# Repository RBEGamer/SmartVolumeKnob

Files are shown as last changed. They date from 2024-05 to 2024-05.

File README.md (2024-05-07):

# SmartVolumeKnob

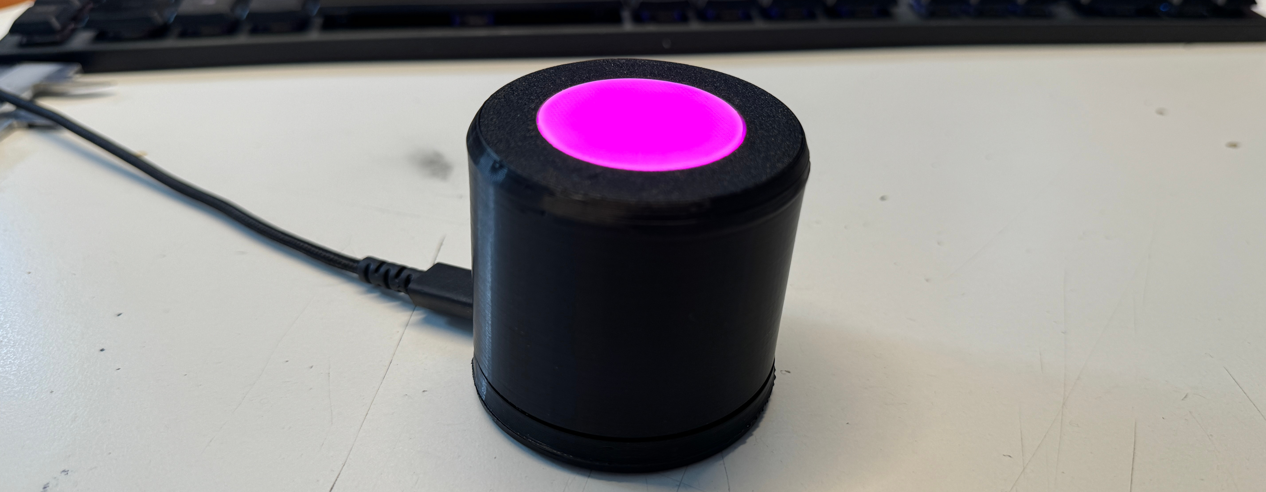
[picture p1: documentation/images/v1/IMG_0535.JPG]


Experience a revolutionary gaming experience with our 3D-printed Fidget Volume Knob!
Bring your music to life and heighten your sensory perception with every twist.
The LED effects add a visual dimension that lights up your room and lifts your mood. Perfect for audiophiles, gamers and anyone who wants to keep their fingers busy.
Get the ultimate companion for your music and gaming session today!

## FEATURES

* Interactive design: Twist, feel and enjoy - The Fidget Volume Knob offers a tactile experience that engages your fingers and stimulates your senses.
High quality material: Made from durable and lightweight 3D printed material that is both sturdy and aesthetically pleasing.
* Compatibility: The Volume Knob is compatible with a wide range of devices, including speaker systems, amplifiers, computers and more. Advanced compatibility allows you to utilize the full potential of your audio equipment.
* Simple setup: Setup is a breeze and requires no special tools. Only a 3D printer some screws and wires are needed for construction. Software is plug&play.
* Ergonomic design: The ergonomic design of the volume knob ensures comfortable handling and a comfortable gaming experience, whether you're listening to music for hours or enjoying intense gaming sessions.
* Stylish design: With its modern and futuristic design, the Fidget Volume Knob is not only a functional accessory, but also an eye-catcher in any room.
* Versatile use: Whether for listening to music, gaming or simply to relieve stress - the Fidget Volume Knob with LED effects is a versatile accessory that is suitable for any occasion. Thanks to the microcontroller used, all kinds of functions can be realized.

## BOM 

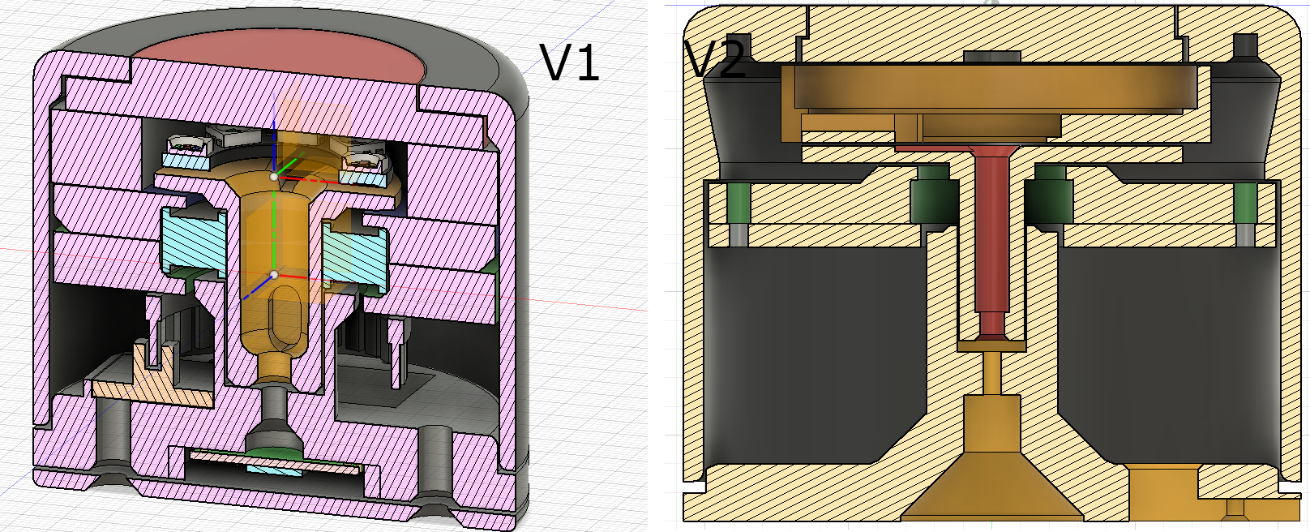
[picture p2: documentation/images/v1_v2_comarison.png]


Currently there are two different versions of the `SmartVolumeKnob` labeled  `v1` and `v2`.
The key difference is the size and complexity of the mechanical strucutre.

`V1` is the small variant of the `SmartVolumeKnob` with a footprint of arounf `60mm` in diameter, but the mechanical parts are designed with limited tolerances.
It uses a 3d printed optical encoder consists of one encoder disc and two light barrier modules to form a incremental encoder.

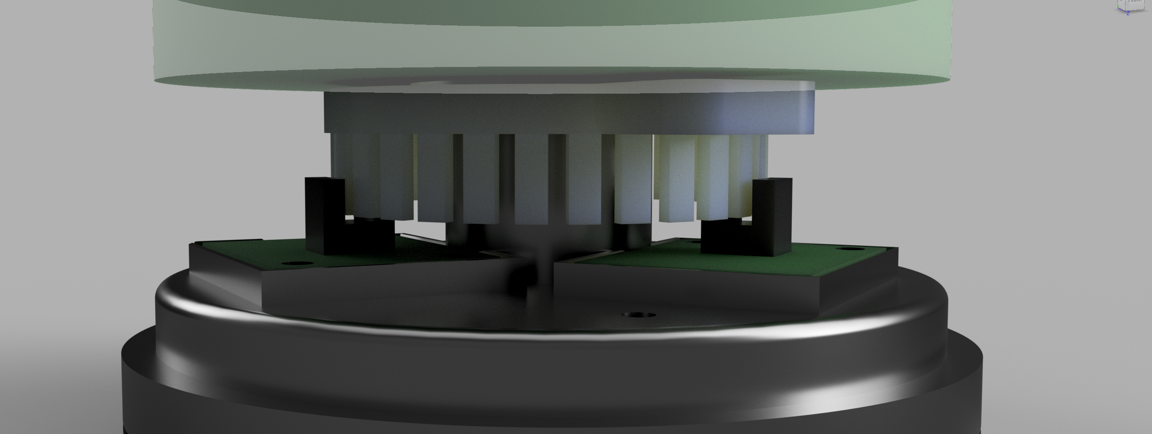
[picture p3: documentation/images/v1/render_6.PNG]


The `V2` is a huge and more simplified design with a footprint of around `110mm` in diameter.
To further simplify the design a magnetic absolute encoder is used here instead of the more complicated diy encoder design.

### GENERAL 3D PRINT SETTINGS AND POST PROCESSING STEPS

* Layer height: 0.2mm or 0.1mm for better shell quality
* Support: Support on buildplate only
* Inflill: 10% - 20%
* The screw holes are designed without any large tolerances. So may run a X-Y compensation on your printer first or drill them to size after printing.

For additional haptic and quality improvement, you can print the * `*_shell.stl` parts using a SLA / SLS printer!

All exported `.stl` files can be found in the `src/cad/<VARIANT>/stl`. All parts as `.step` and the `Fusion360` project files can be found in the parent folder.

After printing all parts use an `debringing tool` on all parts with inner holes ( especially on `bearing_*.stl` parts).

### REQUIRED FILAMENT

For both versions there are at least two different filament colors required. One for the base color of the shell and one for the lightpath (`white`/`transparent`)
For all inner parts the color can be anything, due these are not visible from the outside.
`PLA` is used on all 3D printed parts here. All files are designed for a  `120x120x190mm` buildplate, such as the `Voron V0`.

* accent color for outher shell - `shell_*.stl` and `bottom*.stl`, `baseplate*.stl`
* transparent or white for the lightguide parts - `illuminator_*.stl`
* unspecified color - all other `*.stl` files

### REQUIRED TOOLS

* Soldering Iron
* Cables
* Superglue
* Debringing tool
* Small zip ties
* Some wires to connect the individual modules
* Micro USB cable
  
### V2

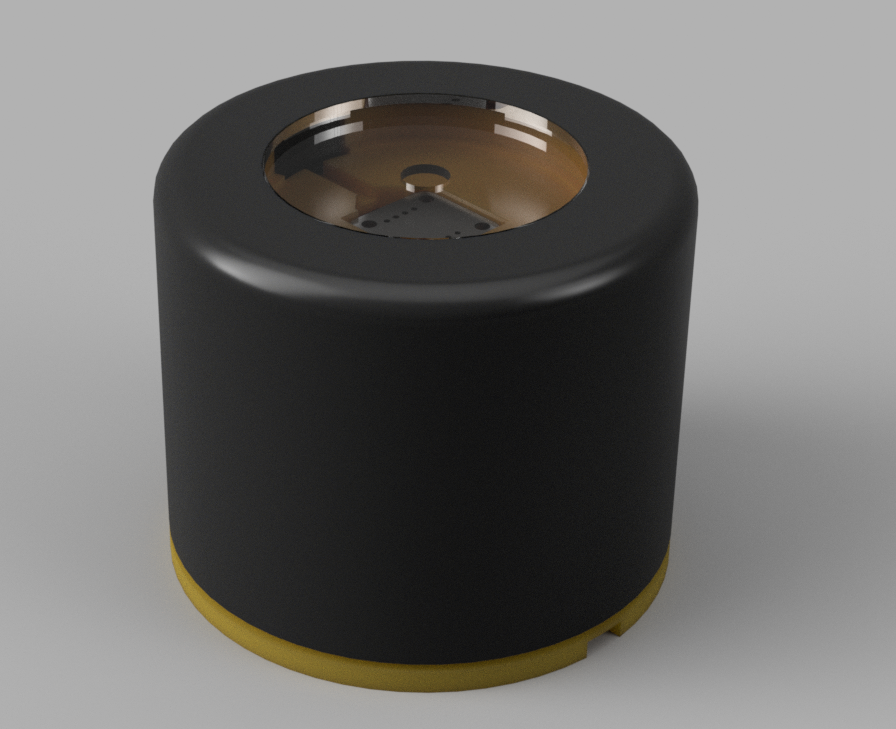
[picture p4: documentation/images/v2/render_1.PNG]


#### 3D PRINTED PARTS

* 1x `electronic_bay.stl`
* 1x `electronic_clamp.stl`
* 1x `bottom.stl`
* 1x `bearing_mount_bottom.stl`
* 1x `bearing_mount_top.stl`
* 1x `illuminator_bearing_connector.stl`
* 1x `illuminator_bottom.stl` - Lightguide - use white or transparent filament!
* 1x `illumniator_top.stl` - Lightguide - use white or transparent filament!
* 1x `outher_shell.stl`
* 1x `illuminator_spacer.stl` - optional but helps a lot with assembly

#### MECHANICAL

* 13x Heat inserts` M3 Short`
* 1x Bearing `6001RS 12mm x 28mm x 8mm`
* 9x `M3x10 FHCS`
* 4x `M3x40 SHCS`
* 2x - 4x `M2x8` to secure the `Raspberry Pi Pico`, or just use a bit of hotglue or superglue
* `aluminium foil` for the light reflector

#### ELECTRICAL

* 1x `Raspberry Pi Pico`
* 21cm of `WS2812 RGB strip` (more LEDs/m equals to  more brightness :)
* 1x `AS5600 Magnetic Angle Encoder` with `diamagnetic magnet`
  
### V1

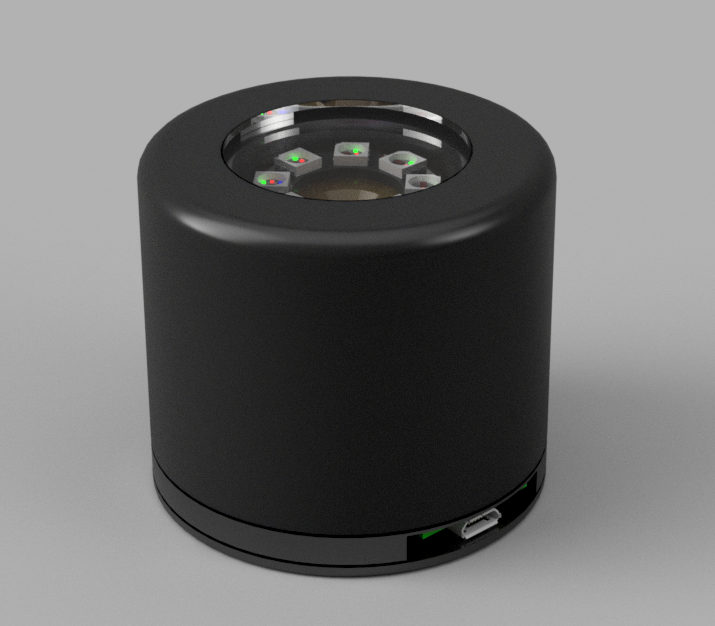
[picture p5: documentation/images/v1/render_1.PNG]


#### 3D PRINTED PARTS

* `baseplate.stl`
* `bearing_clamp_bottom.stl`
* `bearing_clamp_top.stl`
* `bottom_plate.stl`
* `encder_disc.stl` - print with 0.1mm and remove any stringing!
* `illuminator.stl` - Lightguide - use white or transparent filament!
* `illuminator_spacer.stl`
* `led_holder.stl`
* `outher_shell`
    
#### MECHANICAL

* 7x Heat inserts` M3 Short`
* 5x `M3x10 FHCS`
* 2x `M3x25 SHCS`
* 2x - 4x `M2x8` to secure the `Raspberry Pi Pico`, or just use a bit of hotglue or superglue
* 1x Bearing `6001RS 12mm x 28mm x 8mm`

#### ELECTRICAL

* 2x `KY-010`  - Light Barrier Module or 1x `AEDR-8300` optischer optical encoder
* 1x `Raspberry Pi Pico`
* 1x `WS2812 RGB LED Ring 8 LEDs` or `CJMCU-2812-7`

## BUILD INSTRUCTIONS

Please see additional images of the build process located in `documenation/images/<VARIANT>/`.
For further help it is possbile to open the complete assembled cad model `src/cad/<VARIANT>/SmartVolumeKnob.*`.

### V2

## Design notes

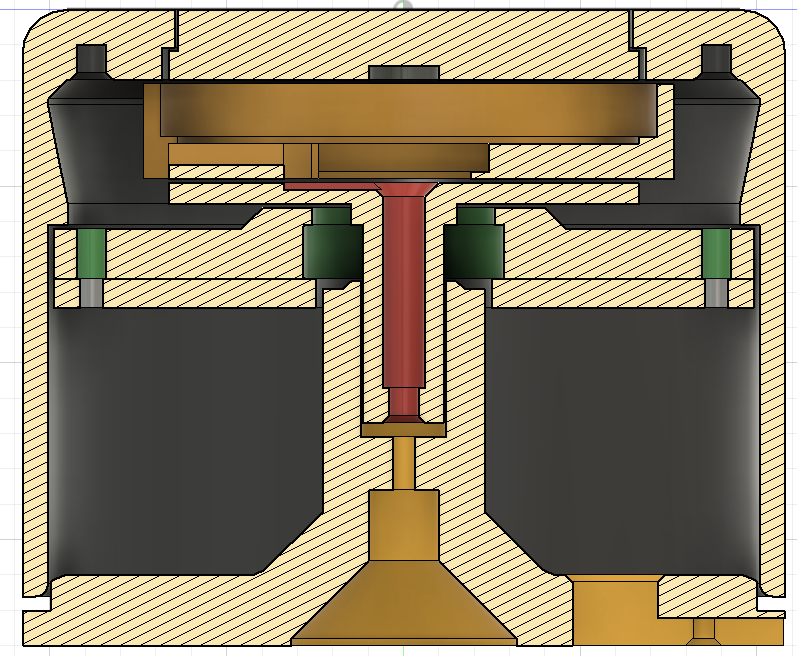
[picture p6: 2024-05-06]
documentation/images/v2/cut_view_v2_1.PNG

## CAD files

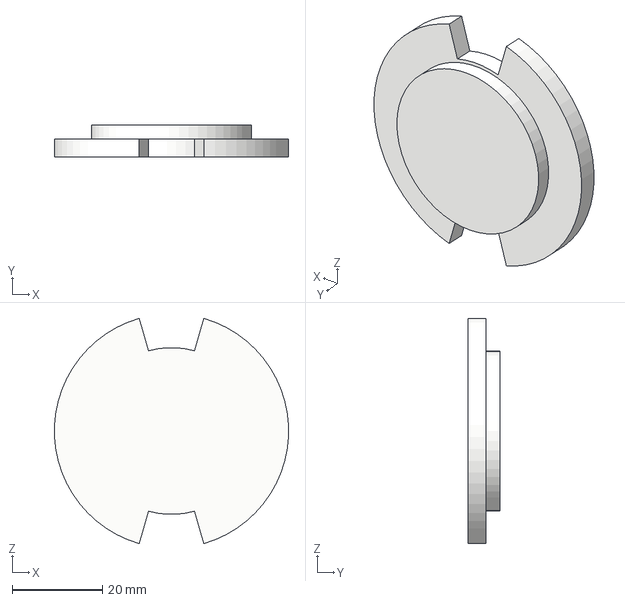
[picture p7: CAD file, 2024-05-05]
src/cad/v1/illuminator.step
51.9 x 7.20 x 50.0 mm

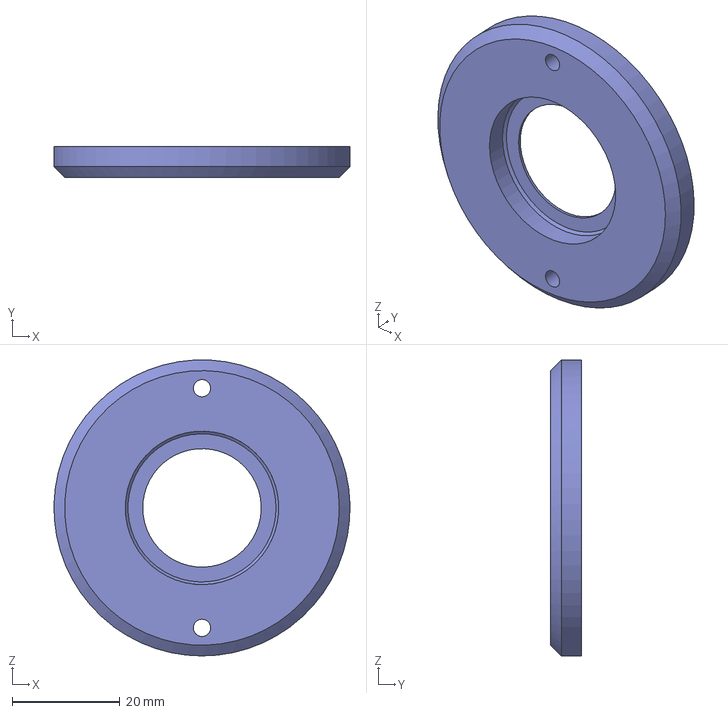
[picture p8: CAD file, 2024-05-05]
src/cad/v1/bearing_clamp_top.step
55.0 x 5.75 x 55.0 mm

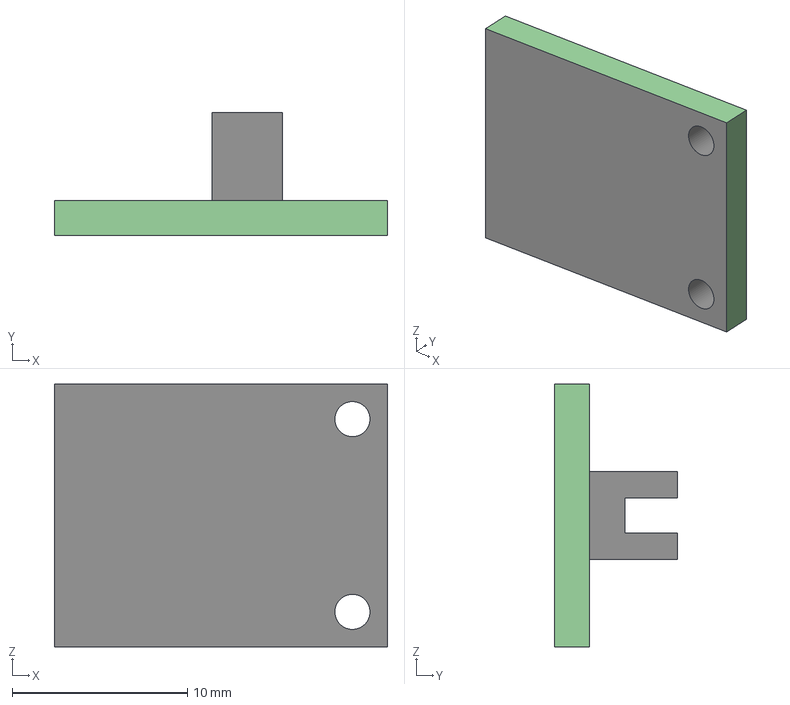
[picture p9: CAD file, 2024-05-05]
src/cad/v1/ky-010 v1.step
19.0 x 7.00 x 15.0 mm

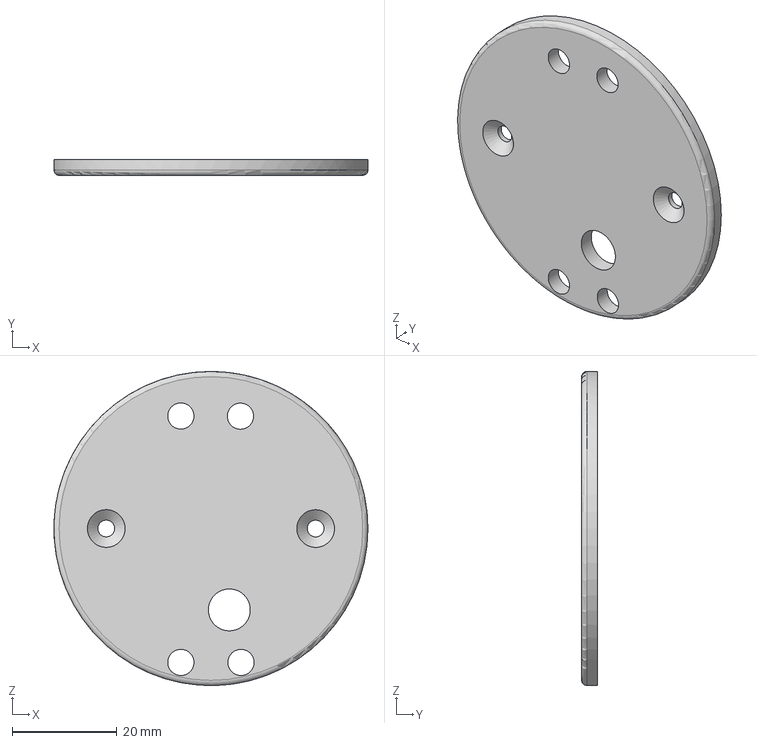
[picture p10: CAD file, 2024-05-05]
src/cad/v1/bottom_plate.step
60.0 x 3.00 x 60.0 mm

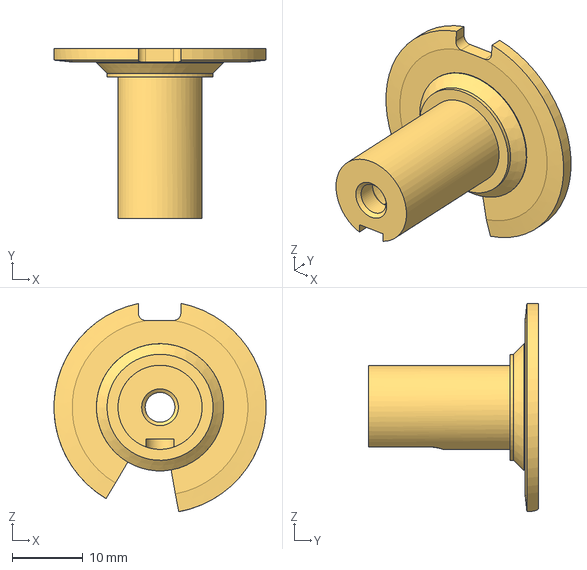
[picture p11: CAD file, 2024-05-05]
src/cad/v1/led_holder.step
30.0 x 24.0 x 29.5 mm

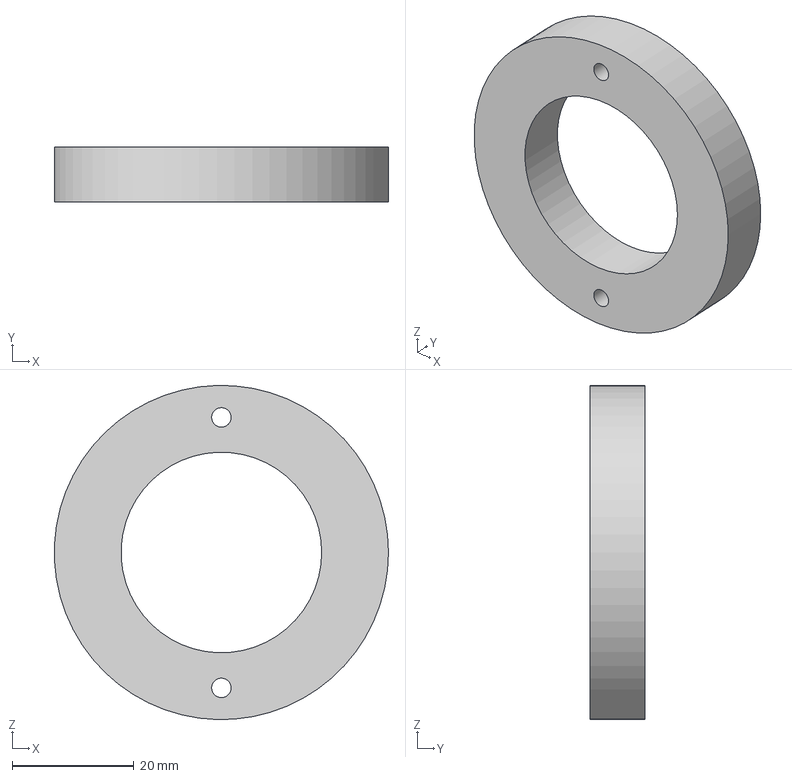
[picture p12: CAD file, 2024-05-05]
src/cad/v1/illuminator_spacer.step
55.0 x 9.00 x 55.0 mm

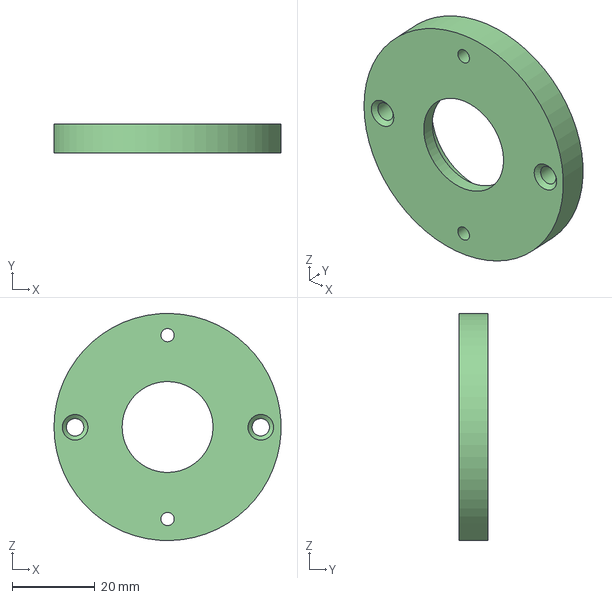
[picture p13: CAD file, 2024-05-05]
src/cad/v1/bearing_clamp_bottom.step
55.0 x 7.00 x 55.0 mm

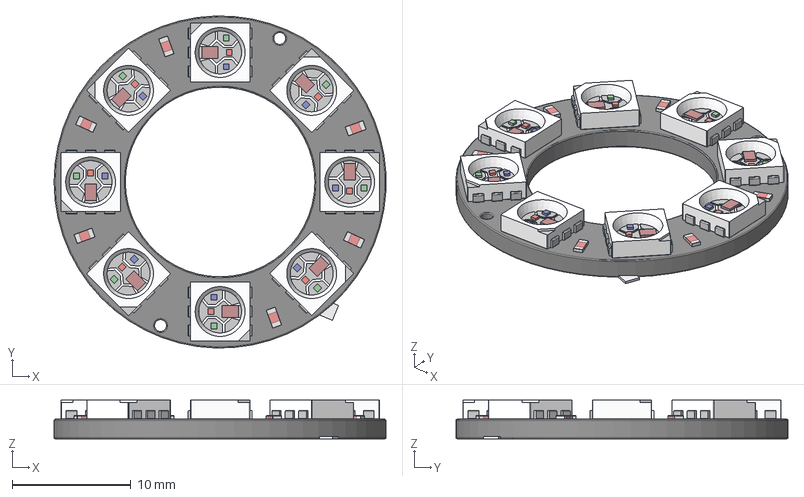
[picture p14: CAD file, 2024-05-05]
src/cad/v1/WS2812 RING 8X v1.step
27.9 x 27.9 x 3.25 mm
Component4(Mirror) (1) x 3
LED WS2812 v1 x 8
CAP0603 v1 x 6

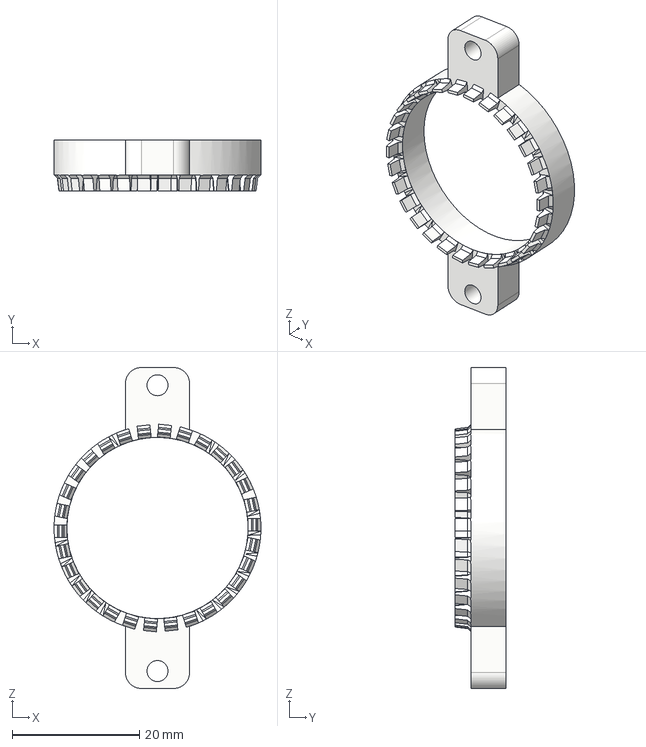
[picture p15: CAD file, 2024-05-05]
src/cad/v1/encder_disc.step
32.5 x 8.10 x 50.5 mm

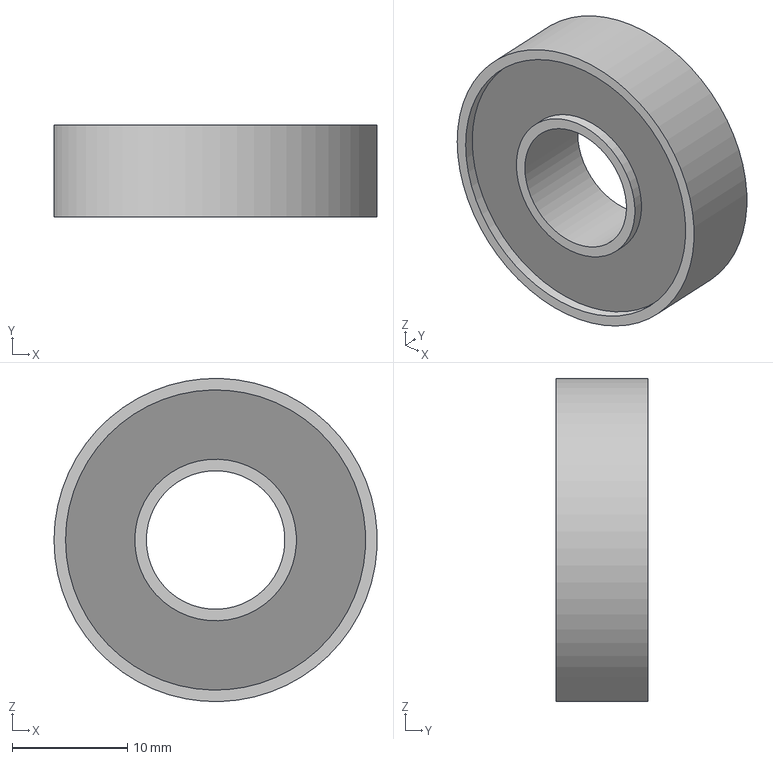
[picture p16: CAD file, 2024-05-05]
src/cad/v1/Beraring.step
28.0 x 8.00 x 28.0 mm

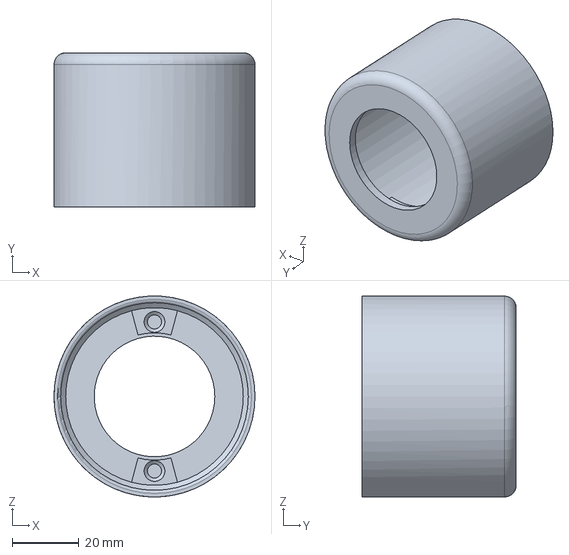
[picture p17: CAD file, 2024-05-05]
src/cad/v1/outher_shell.step
60.0 x 46.1 x 60.0 mm

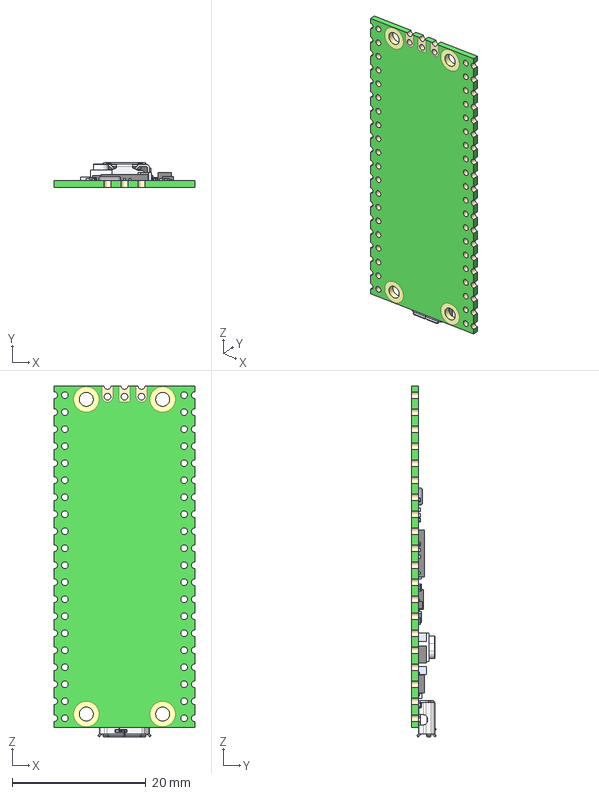
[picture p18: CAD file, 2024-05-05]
src/cad/v1/Raspberry Pi Pico-R3 v1.step
21.0 x 3.69 x 52.4 mm
PCB, Raspberry Pi Pico-R3
MicroUSB Port, Raspberry Pi Pico-R3
RP2040 Microcontroller, Raspberry Pi Pico-R3
SW1, Tact Switch, Raspberry Pi Pico-R3
D1, Diode, Schottky, Raspberry Pi Pico-R3
D2, QSME-C194, LED, Raspberry Pi Pico-R3
L1, Inductor, Raspberry Pi Pico-R3
U2, RT6150B-33GQW, Buck Boost Converter, Raspberry Pi Pico-R3
U3, W25Q16JVUXIQ, Serial NOR Flash 16 Mbit, Raspberry Pi Pico-R3
Q1, MOSFET, DMG1012T, Raspberry Pi Pico-R3
X1, X12M000000S096, 12 Mhz Crystal Resonator, Raspberry Pi Pico-R3
SMD Resistor, Configurable, Raspberry Pi Pico-R3_R1
SMD Resistor, Configurable, Raspberry Pi Pico-R3_R2
SMD Resistor, Configurable, Raspberry Pi Pico-R3_R3
SMD Resistor, Configurable, Raspberry Pi Pico-R3_R4
SMD Resistor, Configurable, Raspberry Pi Pico-R3_R5
SMD Resistor, Configurable, Raspberry Pi Pico-R3_R6
SMD Resistor, Configurable, Raspberry Pi Pico-R3_R7
SMD Resistor, Configurable, Raspberry Pi Pico-R3_R8
SMD Resistor, Configurable, Raspberry Pi Pico-R3_R9
SMD Resistor, Configurable, Raspberry Pi Pico-R3_R10
SMD Resistor, Configurable, Raspberry Pi Pico-R3_R11
SMD Resistor, Configurable, Raspberry Pi Pico-R3_R12
SMD Resistor, Configurable, Raspberry Pi Pico-R3_R13
SMD Resistor, Configurable, Raspberry Pi Pico-R3_R14
SMD Resistor, Configurable, Raspberry Pi Pico-R3_R15
SMD Capacitor, Configurable, Raspberry Pi Pico-R3_C1
SMD Capacitor, Configurable, Raspberry Pi Pico-R3_C2
SMD Capacitor, Configurable, Raspberry Pi Pico-R3_C3
SMD Capacitor, Configurable, Raspberry Pi Pico-R3_C4
SMD Capacitor, Configurable, Raspberry Pi Pico-R3_C5
SMD Capacitor, Configurable, Raspberry Pi Pico-R3_C6
SMD Capacitor, Configurable, Raspberry Pi Pico-R3_C7
SMD Capacitor, Configurable, Raspberry Pi Pico-R3_C8
SMD Capacitor, Configurable, Raspberry Pi Pico-R3_C9
SMD Capacitor, Configurable, Raspberry Pi Pico-R3_C10
SMD Capacitor, Configurable, Raspberry Pi Pico-R3_C11
SMD Capacitor, Configurable, Raspberry Pi Pico-R3_C12
SMD Capacitor, Configurable, Raspberry Pi Pico-R3_C13
SMD Capacitor, Configurable, Raspberry Pi Pico-R3_C14
SMD Capacitor, Configurable, Raspberry Pi Pico-R3_C15
SMD Capacitor, Configurable, Raspberry Pi Pico-R3_C16
SMD Capacitor, Configurable, Raspberry Pi Pico-R3_C17
SMD Capacitor, Configurable, Raspberry Pi Pico-R3_C18

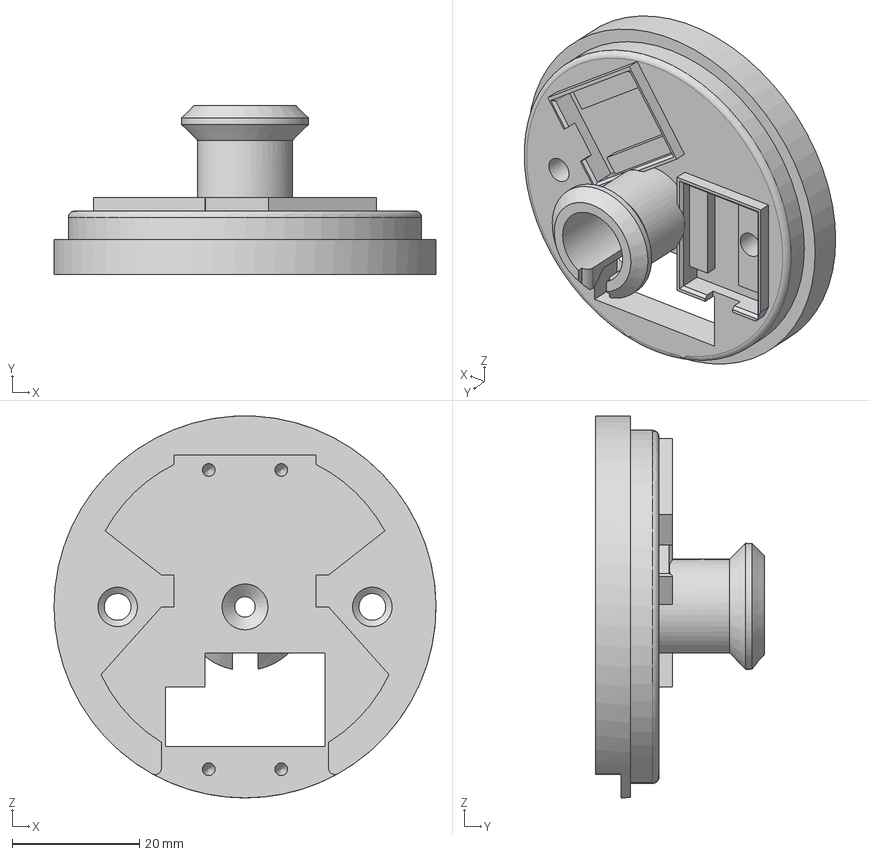
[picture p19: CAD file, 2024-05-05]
src/cad/v1/baseplate.step
60.0 x 26.6 x 60.0 mm

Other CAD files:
src/cad/v1/stl/baseplate.stl
src/cad/v1/stl/bearing_clamp_bottom.stl
src/cad/v1/stl/bearing_clamp_top.stl
src/cad/v1/stl/bottom_plate.stl
src/cad/v1/stl/encder_disc.stl
src/cad/v1/stl/illuminator.stl
src/cad/v1/stl/illuminator_spacer.stl
src/cad/v1/stl/led_holder.stl
src/cad/v1/stl/outher_shell.stl

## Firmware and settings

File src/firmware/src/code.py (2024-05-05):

import usb_hid
from adafruit_hid.keyboard import Keyboard
from adafruit_hid.keycode import Keycode
from adafruit_hid.consumer_control import ConsumerControl
from adafruit_hid.consumer_control_code import ConsumerControlCode

import rotaryio
import board
import random
import time
import digitalio
from static_modules import ledring
from static_modules import config
from static_modules import helper



# CONSTANTS
LED_FADE_TIMEOUT_TIME: int = 1
USER_INTERACTION_TIMEOUT_TIME: int = 2000 #FADE LEDS DOWN AFTER x SECONDS OF INATIVITY
MAX_LED_HSV_VALUE: int = 100 # FOR SCALING BACK FROM 0-X => 0-1.0

# VARIABLES
encoder_middle_point: int = 1
current_led_h: int = 0
current_led_v: int = 0
target_led_h: int = random.randrange(0, MAX_LED_HSV_VALUE+1)
target_led_v: int = 100

def handle_encoder_change(_direction: int = 0, _amount: int = 1):
    global target_led_h
    global target_led_v
    global current_led_h
    global current_led_v
    
    for i in range(_amount):
        if _direction > 0:
            consumer.send(ConsumerControlCode.VOLUME_INCREMENT)
        elif _direction < 0:
            consumer.send(ConsumerControlCode.VOLUME_DECREMENT)
    
    target_led_h = (target_led_h +(_direction*_amount)) % MAX_LED_HSV_VALUE
    target_led_v = MAX_LED_HSV_VALUE
    
    
    #current_led_h = target_led_h
    print("hec", _direction, _amount, target_led_h)





# SETUP USB REMOTE CONTROL
consumer = ConsumerControl(usb_hid.devices)
kbd = Keyboard(usb_hid.devices)
consumer.send(ConsumerControlCode.VOLUME_DECREMENT)


# INIT LED RING
ledring.ledring().clear()


## REGISTER ENCODER BUTTON EVENTS BY REMAPPING THE ENCODER SWITCH 
#pina = digitalio.DigitalInOut(config.CFG_ENCODER_CLK_PIN)
#pinb = digitalio.DigitalInOut(config.CFG_ENCODER_DT_PIN)
encoder = rotaryio.IncrementalEncoder(config.CFG_ENCODER_CLK_PIN, config.CFG_ENCODER_DT_PIN)
# CONFIGURE ENCODER



def exec():
    print("exec")
    global target_led_h
    global target_led_v
    global current_led_h
    global current_led_v
    global encoder_middle_point
    last_update: int = helper.millis()
    last_userinteraction_update: int = helper.millis()
    current_encoder_value: int = encoder_middle_point
    force_fade: bool = False # USED TO AVOID FLICKERING WHEN LED OFF FADE IS ACTIVE DUE TO USER INTERACTION TIME TIMEOUT
    while True:
    


        # HANDLE ENCODER
        current_encoder_value = encoder.position
        #print(pina.value, pinb.value)
        #print(current_encoder_value)
        if current_encoder_value != encoder_middle_point:
            print(current_encoder_value)
            
            last_userinteraction_update = helper.millis()
                
            if current_encoder_value > encoder_middle_point:
                handle_encoder_change(-1, current_encoder_value)
            elif current_encoder_value < encoder_middle_point:
                handle_encoder_change(1, current_encoder_value)
            
            encoder_middle_point = current_encoder_value
                
         # HANDLE LED INACTIVITY FADEt
        if abs(helper.millis() - last_userinteraction_update) > USER_INTERACTION_TIMEOUT_TIME:
            #last_userinteraction_update = helper.millis()
            
            if target_led_v > 0:
                target_led_v = target_led_v - 1
                #print(target_led_v)
                force_fade = True
        else:
            if force_fade:
                # START WITH A NEW RANDOM COLOR NEXT TIME THE USER INTERACTS WITH THE SYSTEM
                target_led_h = random.randrange(0, MAX_LED_HSV_VALUE+1)
                force_fade = False
                
        # HANDLE LED FADING
        if  abs(last_update - helper.millis()) > LED_FADE_TIMEOUT_TIME or force_fade:
            last_update = helper.millis()
            # FADE HUE
            if target_led_h > current_led_h:
                current_led_h = current_led_h + 1
            if target_led_h < current_led_h:
                current_led_h = current_led_h - 1

            # FADE BRIGHNESS
            if target_led_v > current_led_v:
                current_led_v = current_led_v + 1
            if target_led_v < current_led_v:
                current_led_v = current_led_v - 1

       

        # UPDATE LED
        # SCALE 0-100 to 0.1
        ledring.ledring().set_neopixel_full_hue_value(abs(current_led_h / MAX_LED_HSV_VALUE), abs(current_led_v / MAX_LED_HSV_VALUE))         
        time.sleep(0.01)

        
exec()

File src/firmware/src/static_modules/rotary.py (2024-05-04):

# MIT License (MIT)
# Copyright (c) 2022 Mike Teachman
# Modified by Marcel Ochsendorf 2024
# https://opensource.org/licenses/MIT

# Platform-independent MicroPython code for the rotary encoder module

# Documentation:
#   https://github.com/MikeTeachman/micropython-rotary

import micropython

_DIR_CW = const(0x10)  # Clockwise step
_DIR_CCW = const(0x20)  # Counter-clockwise step

# Rotary Encoder States
_R_START = const(0x0)
_R_CW_1 = const(0x1)
_R_CW_2 = const(0x2)
_R_CW_3 = const(0x3)
_R_CCW_1 = const(0x4)
_R_CCW_2 = const(0x5)
_R_CCW_3 = const(0x6)
_R_ILLEGAL = const(0x7)

_transition_table = [

    # |------------- NEXT STATE -------------|            |CURRENT STATE|
    # CLK/DT    CLK/DT     CLK/DT    CLK/DT
    #   00        01         10        11
    [_R_START, _R_CCW_1, _R_CW_1,  _R_START],             # _R_START
    [_R_CW_2,  _R_START, _R_CW_1,  _R_START],             # _R_CW_1
    [_R_CW_2,  _R_CW_3,  _R_CW_1,  _R_START],             # _R_CW_2
    [_R_CW_2,  _R_CW_3,  _R_START, _R_START | _DIR_CW],   # _R_CW_3
    [_R_CCW_2, _R_CCW_1, _R_START, _R_START],             # _R_CCW_1
    [_R_CCW_2, _R_CCW_1, _R_CCW_3, _R_START],             # _R_CCW_2
    [_R_CCW_2, _R_START, _R_CCW_3, _R_START | _DIR_CCW],  # _R_CCW_3
    [_R_START, _R_START, _R_START, _R_START]]             # _R_ILLEGAL

_transition_table_half_step = [
    [_R_CW_3,            _R_CW_2,  _R_CW_1,  _R_START],
    [_R_CW_3 | _DIR_CCW, _R_START, _R_CW_1,  _R_START],
    [_R_CW_3 | _DIR_CW,  _R_CW_2,  _R_START, _R_START],
    [_R_CW_3,            _R_CCW_2, _R_CCW_1, _R_START],
    [_R_CW_3,            _R_CW_2,  _R_CCW_1, _R_START | _DIR_CW],
    [_R_CW_3,            _R_CCW_2, _R_CW_3,  _R_START | _DIR_CCW],
    [_R_START,           _R_START, _R_START, _R_START],
    [_R_START,           _R_START, _R_START, _R_START]]

_STATE_MASK = const(0x07)
_DIR_MASK = const(0x30)


def _wrap(value, incr, lower_bound, upper_bound):
    range = upper_bound - lower_bound + 1
    value = value + incr

    if value < lower_bound:
        value += range * ((lower_bound - value) // range + 1)

    return lower_bound + (value - lower_bound) % range


def _bound(value, incr, lower_bound, upper_bound):
    return min(upper_bound, max(lower_bound, value + incr))


def _trigger(rotary_instance):
    for listener in rotary_instance._listener:
        listener()


class Rotary(object):

    RANGE_UNBOUNDED = const(1)
    RANGE_WRAP = const(2)
    RANGE_BOUNDED = const(3)

    def __init__(self, min_val, max_val, incr, reverse, range_mode, half_step, invert):
        self._min_val = min_val
        self._max_val = max_val
        self._incr = incr
        self._reverse = -1 if reverse else 1
        self._range_mode = range_mode
        self._value = min_val
        self._state = _R_START
        self._half_step = half_step
        self._invert = invert
        self._listener = []

    def set(self, value=None, min_val=None, incr=None,
            max_val=None, reverse=None, range_mode=None):
        # disable DT and CLK pin interrupts
        self._hal_disable_irq()

        if value is not None:
            self._value = value
        if min_val is not None:
            self._min_val = min_val
        if max_val is not None:
            self._max_val = max_val
        if incr is not None:
            self._incr = incr
        if reverse is not None:
            self._reverse = -1 if reverse else 1
        if range_mode is not None:
            self._range_mode = range_mode
        self._state = _R_START

        # enable DT and CLK pin interrupts
        self._hal_enable_irq()

    def value(self):
        return self._value

    def set_current_value(self, _value):
        self._value = _value

    def reset(self):
        self._value = 0

    def close(self):
        self._hal_close()

    def add_listener(self, l):
        self._listener.append(l)

    def remove_listener(self, l):
        if l not in self._listener:
            raise ValueError('{} is not an installed listener'.format(l))
        self._listener.remove(l)
        
    def _process_rotary_pins(self, pin):
        old_value = self._value
        clk_dt_pins = (self._hal_get_clk_value() <<
                       1) | self._hal_get_dt_value()
                       
        if self._invert:
            clk_dt_pins = ~clk_dt_pins & 0x03
            
        # Determine next state
        if self._half_step:
            self._state = _transition_table_half_step[self._state &
                                                      _STATE_MASK][clk_dt_pins]
        else:
            self._state = _transition_table[self._state &
                                            _STATE_MASK][clk_dt_pins]
        direction = self._state & _DIR_MASK

        incr = 0
        if direction == _DIR_CW:
            incr = self._incr
        elif direction == _DIR_CCW:
            incr = -self._incr

        incr *= self._reverse

        if self._range_mode == self.RANGE_WRAP:
            self._value = _wrap(
                self._value,
                incr,
                self._min_val,
                self._max_val)
        elif self._range_mode == self.RANGE_BOUNDED:
            self._value = _bound(
                self._value,
                incr,
                self._min_val,
                self._max_val)
        else:
            self._value = self._value + incr

        try:
            if old_value != self._value and len(self._listener) != 0:
                _trigger(self)
        except:
            pass

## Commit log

2024-05-04 added circuit python required restrucutring
2024-05-05 led fade fixed
2024-05-05 added cad stl
    [Beraring.step, Raspberry Pi Pico-R3 v1.step, WS2812 RING 8X v1.step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]
